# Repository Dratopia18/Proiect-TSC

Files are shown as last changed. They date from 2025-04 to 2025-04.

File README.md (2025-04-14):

# Proiect-TSC

# Diagrama Proiectului
<pre lang="markdown"> 
+-------------------------------------------+
|              POWER SECTION                |
|  +-------------+       +-----------------+|
|  | USB Type-C  |       | Charging Circuit||
|  | Connector   |------>| MCP73831        ||
|  | USB4110-GF-A|       | (Battery Mgmt)  ||
|  +-------------+       +-----------------+|
|         |                      |          |
|         v                      v          |
|  +-------------+       +-----------------+|
|  | USB to 3.3V |       | Battery Monitor ||
|  | XC6220A331MR|       | MAX17048G       ||
|  | (LDO Reg)   |       | (Fuel Gauge)    ||
|  +-------------+       +-----------------+|
|         |                                 |
+---------|---------------------------------+
          |
          v
+-----------------+        +-------------------+        +----------------+
| Interface       |        | Main Controller   |        | Memory         |
| +-------------+ |        | +---------------+ |        | +-----------+  |
| | microSD Card| |<------>| | ESP32-C6      | |<------>| | W25Q512J  |  |
| | Slot        | |        | | WROOM Module  | |        | | Flash     |  |
| +-------------+ |        | +---------------+ |        | | (64MB)    |  |
|                 |        |         |         |        |             |  |
| +-------------+ |        |         |         |        | +-----------+  |
| | FPC/FFC     | |<-------+         |         +------->| | DS3231    |  |
| | Connector   | |        |         |         |        | | RTC       |  |
| | (24-pin)    | |        |         v         |        | | w/Battery |  |
| +-------------+ |        | +---------------+ |        +----------------+
+-----------------+        | | Control Logic | |
                           | | Buttons       | |
                           | | (Reset/Boot)  | |
                           | +---------------+ |
                           +-------------------+
                                    |
                                    v
                           +-------------------+
                           | Peripherals       |
                           | +--------------+  |
                           | | BME680       |  |
                           | | Environment  |  |
                           | | Sensor (I2C) |  |
                           | +--------------+  |
                           |                   |
                           | +--------------+  |
                           | | QWIIC/I2C    |  |
                           | | Connector    |  |
                           | +--------------+  |
                           +-------------------+
</pre>

# Tabela BOM a proiectului
| Nr. | Componentă | Descriere | Furnizor | Link Achiziție | Datasheet |
|-----|---|---|---|---|---|
| 1 | ESP32-C6-WROOM-1-N8 | Microcontroller ESP32-C6 cu WiFi 6 și Bluetooth 5 | Digikey | https://www.digikey.com/en/products/detail/espressif-systems/ESP32-C6-WROOM-1-N8/17728866 | https://www.espressif.com/sites/default/files/documentation/esp32-c6-wroom-1_wroom-1u_datasheet_en.pdf |
| 2 | BME680 | Senzor integrat de mediu (temperatură, umiditate, presiune, gaz) | Digikey | https://www.digikey.com/en/products/detail/bosch-sensortec/BME680/7401317 | https://www.bosch-sensortec.com/media/boschsensortec/downloads/datasheets/bst-bme680-ds001.pdf |
| 3 | SD0805S020S1R0 | Diodă Schottky Barrier | Mouser | [https://www.mouser.com/ProductDetail/581-SD0805S020S1R0](https://ro.mouser.com/ProductDetail/KYOCERA-AVX/SD0805S020S1R0?qs=jCA%252BPfw4LHbpkAoSnwrdjw%3D%3D) | [http://datasheets.avx.com/schottky.pdf](https://ro.mouser.com/datasheet/2/40/schottky-3165252.pdf) |
| 4 | CPH3225A | Condensator 0.011F 3.3V 1210 | Digikey | https://www.digikey.com/en/products/detail/murata-electronics/CPH3225A/8692444 | [https://product.tdk.com/info/en/catalog/datasheets/mlcc_commercial_general_en.pdf](https://mm.digikey.com/Volume0/opasdata/d220001/medias/docus/6537/rev05-CPHCPM.pdf) |
| 5 | XC6220A331MR_G | Regulator de tensiune LDO | Digikey | https://www.digikey.com/en/products/detail/torex-semiconductor-ltd/XC6220A331MR-G/10165775 | https://www.torexsemi.com/file/xc6220/XC6220.pdf |
| 6 | SI1308EDL_T1_GE3 | Tranzistor MOSFET N-Channel | Digikey | https://www.digikey.com/en/products/detail/vishay-siliconix/SI1308EDL-T1-GE3/4876435 | https://www.vishay.com/docs/68734/si1308edl.pdf |
| 7 | CSR0402JTR470 | Rezistor 47 Ohm 0402 | Digikey | https://www.digikey.com/en/products/detail/stackpole-electronics-inc/CSR0402JTR470/6270526 | https://www.seielect.com/catalog/sei-rmcf_rmcp.pdf |
| 8 | KMS231GPLFS | Switch tactil | Mouser | [https://www.mouser.com/ProductDetail/611-KMS231GPLFS](https://ro.mouser.com/ProductDetail/CK/KMS231GP-LFS?qs=Qe4e1uPWiB2lCKabCZjjQg%3D%3D) | https://www.ckswitches.com/media/1464/kms.pdf |
| 9 | PGB1010603MR | Diodă de protecție ESD | Digikey | https://www.digikey.com/en/products/detail/littelfuse-inc/PGB1010603MR/715755 | https://www.littelfuse.com/~/media/electronics/datasheets/polymer_esd_suppressors/littelfuse_polymer_esd_suppressor_pgb_datasheet.pdf |
| 10 | CC0805KKX7R9BB105 | Condensator ceramic 1μF 50V | Digikey | https://www.digikey.com/en/products/detail/yageo/CC0805KKX7R9BB105/5195292 | https://www.yageo.com/upload/media/product/productsearch/datasheet/mlcc/UPY-GPHC_X7R_6.3V-to-50V_18.pdf |
| 11 | C1206C105K5RAC | Condensator ceramic 1μF 50V 1206 | Mouser | [https://www.mouser.com/ProductDetail/80-C1206C105K5R](https://ro.mouser.com/ProductDetail/KEMET/C1206C105K5RAC?qs=NTAB53G5bVDYFBtoIe7UwQ%3D%3D) | https://www.yageo.com/upload/media/product/productsearch/datasheet/mlcc/UPY-GPHC_X7R_6.3V-to-50V_18.pdf |
| 12 | C0402C105Z9VACTU | Condensator ceramic 1μF 10V 0402 | Mouser | [https://www.mouser.com/ProductDetail/80-C0402C105Z9VAC](https://ro.mouser.com/ProductDetail/KEMET/C0402C105Z9VACTU?qs=gt1LBUVyoHlQieoJt4iw1w%3D%3D) | https://www.yageo.com/upload/media/product/productsearch/datasheet/mlcc/UPY-GPHC_X5R_4V-to-50V_25.pdf |
| 13 | TAJB107K010RNJ | Condensator tantalum 100μF 10V | Digikey | https://www.digikey.com/en/products/detail/kyocera-avx/TAJB107K010RNJ/9748493 | https://componentsearchengine.com/Datasheets/1/TAJB107K010RNJ.pdf |
| 14 | C0402C475M9PACTU | Condensator ceramic 4.7μF 6.3V 0402 | Mouser | [https://www.mouser.com/ProductDetail/80-C0402C475M9PAC](https://ro.mouser.com/ProductDetail/KEMET/C0402C475M9PACTU?qs=x4XeXhDQKnr0GX0Xu9DUoQ%3D%3D) | https://www.yageo.com/upload/media/product/productsearch/datasheet/mlcc/UPY-GPHC_Y5V_6.3V-to-50V_20.pdf |
| 15 | DMG2305UX_7 | Tranzistor MOSFET P-Channel | Digikey | https://www.digikey.com/en/products/detail/diodes-incorporated/DMG2305UX-7/4340667 | https://www.diodes.com/assets/Datasheets/DMG2305UX.pdf |
| 16 | WCR0402-100KFA | Rezistor 100k Ohm 0402 | Mouser | [https://www.mouser.com/ProductDetail/652-WCR0402-100KFA](https://ro.mouser.com/ProductDetail/Welwyn-Components-TT-Electronics/WCR0402-100KFA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) | https://www.welwyn-tt.com/wp-content/uploads/2020/07/Welwyn_WCR_Series_-_Issue_5_-_April_2020.pdf |
| 17 | PFMF.050.2 | Siguranță PTC resetabilă | Mouser | [https://www.mouser.com/ProductDetail/652-PFMF.050.2](https://ro.mouser.com/ProductDetail/Schurter/PFMF.050.2?qs=1auRipcfynCums5v1iucSA%3D%3D) | https://www.littelfuse.com/~/media/electronics/datasheets/resettable_ptcs/littelfuse_ptc_pfmf_datasheet.pdf |
| 18 | 744043680 | Inductor de putere 68μH | Mouser | [https://www.mouser.com/ProductDetail/710-744043680](https://ro.mouser.com/ProductDetail/Wurth-Elektronik/744043680?qs=PGXP4M47uW6VkZq%252BkzjrHA%3D%3D) | https://www.we-online.com/components/products/datasheet/744043680.pdf |
| 19 | MBR0530T3G | Diodă Schottky 0.5A 30V | Mouser | [https://www.mouser.com/ProductDetail/863-MBR0530T3G](https://ro.mouser.com/ProductDetail/onsemi/MBR0530T3G?qs=3JMERSakebpEmdUS6GetdQ%3D%3D) | https://www.onsemi.com/pdf/datasheet/mbr0530t1-d.pdf |
| 20 | SM04B_SRSS_TB | Conector JST SH 4 pini SMD | Digikey | https://www.digikey.com/en/products/detail/jst-sales-america-inc/SM04B-SRSS-TB-LF-SN/926710 | https://www.jst-mfg.com/product/pdf/eng/eSH.pdf |
| 21 | MAX17048G_T10 | Monitor de baterie Li+ | Digikey | https://www.digikey.com/en/products/detail/analog-devices-inc-maxim-integrated/MAX17048G-T10/3758921 | https://datasheets.maximintegrated.com/en/ds/MAX17048-MAX17049.pdf |
| 22 | MCP73831T_2ACI_OT | Controller de încărcare Li-Ion/Li-Polymer | Digikey | https://www.digikey.com/en/products/detail/microchip-technology/MCP73831T-2ACI-OT/964301 | https://ww1.microchip.com/downloads/en/DeviceDoc/MCP73831-Family-Data-Sheet-DS20001984H.pdf |
| 23 | BD5229G-TR | Detector de tensiune cu timp de întârziere ajustabil | Digikey | https://www.digikey.com/en/products/detail/rohm-semiconductor/BD5229G-TR/658502 | https://fscdn.rohm.com/en/products/databook/datasheet/ic/power/voltage_detector/bd52xxg-e.pdf |
| 24 | DS3231SN# | RTC (Real Time Clock) Serial | Digikey | https://www.digikey.com/en/products/detail/analog-devices-inc-maxim-integrated/DS3231SN/1197576 | https://datasheets.maximintegrated.com/en/ds/DS3231.pdf |
| 25 | W25Q512JVEIQ | Memorie Flash SPI 512Mbit | Digikey | https://www.digikey.com/en/products/detail/winbond-electronics/W25Q512JVEIQ/10244706 | https://www.winbond.com/resource-files/w25q512jv%20revf%2010142020%20plus.pdf |
| 26 | FH34SRJ-24S-0.5SH(99) | Conector FPC 24 pini | Mouser | [https://www.mouser.com/ProductDetail/798-FH34SRJ24S05SH99](https://ro.mouser.com/ProductDetail/Hirose-Connector/FH34SRJ-24S-0.5SH99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) | https://www.hirose.com/product/document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 |
| 27 | C0402C104K4RACTU | Condensator ceramic 0.1μF 16V 0402 | Digikey | https://www.digikey.com/en/products/detail/kyocera-avx/C0402C104K4RACTU/789653 | https://ds.yuden.co.jp/TYCOMPAS/ut/download?pn=CC0402JRNPO9BN220&fileType=CA |
| 28 | USBLC6-2SC6Y | Circuit de protecție ESD pentru USB | Digikey | https://www.digikey.com/en/products/detail/stmicroelectronics/USBLC6-2SC6Y/2819177 | https://www.st.com/resource/en/datasheet/usblc6-2.pdf |
| 29 | USB4110-GF-A | Conector USB Type-C | Digikey | https://www.digikey.com/en/products/detail/gct/USB4110-GF-A/10384547 | https://gct.co/connector/usb4110 |
| 30 | 112A-TAAR-R03 | Conector pentru antenă | Digikey | https://www.digikey.com/en/products/detail/linx-technologies-inc/112A-TAAR-R03/17633923 | https://linxtechnologies.com/wp/wp-content/uploads/112-series-data-sheet.pdf |

# Descrierea Funcționalității Hardware

## Modulul Microcontroller

Proiectul este bazat pe modulul ESP32-C6-WROOM-1-N8, un microcontroller de ultimă generație care include WiFi 6 și Bluetooth 5. Acest modul oferă performanțe excelente și un consum de energie redus, fiind ideal 
pentru aplicații IoT.

## Senzori

BME680 - un senzor integrat de mediu produs de Bosch Sensortec care măsoară:

* Temperatura (între -40°C și +85°C)
* Umiditatea relativă (între 0% și 100%)
* Presiunea barometrică (între 300hPa și 1100hPa)
* Calitatea aerului (prin măsurarea compușilor organici volatili)

Senzorul se conectează la ESP32-C6 prin interfața I2C, utilizând pinii SDA și SCL.

DS3231SN - un Real Time Clock (RTC) de înaltă precizie:

* Menține data și ora precisă
* Include compensare de temperatură
* Interfațare prin I2C
* Backup cu baterie pentru păstrarea timpului când alimentarea principală este întreruptă

## Sistemul de Alimentare

Încărcător de baterie Li-Ion/Li-Polymer:

* Controller dedicat MCP73831T-2ACI-OT
* LED indicator pentru starea încărcării
* Circuite de protecție pentru baterie

Management Energie:

* Regulator LDO XC6220A331MR_G pentru alimentare stabilă 3.3V
* Detector de tensiune BD5229G-TR pentru monitorizarea nivelului bateriei
* Monitor de baterie MAX17048G_T10 pentru măsurarea precisă a nivelului de încărcare
* Circuite de protecție PTC (PFMF.050.2) pentru protecție la supracurent

Convertoare DC-DC:
* Inductori de putere (744043680) pentru conversia eficientă a tensiunii
* Diode Schottky (SD0805S020S1R0, MBR0530T3G) pentru circuitele de comutație

## Stocare
Sistemul include memoria flash W25Q512JVEIQ de 512Mbit (64MB) conectată prin interfața SPI, oferind:

* Spațiu amplu pentru logging de date
* Viteză mare de citire/scriere (până la 104 MHz în mod SPI)
* Suport pentru modul Quad SPI pentru transfer de date accelerat
* Durată de retenție a datelor de peste 20 de ani

## Conectivitate

USB Type-C:

* Conector USB4110-GF-A pentru încărcare și comunicare
* Circuit de protecție USBLC6-2SC6Y pentru protecție ESD
* Suport pentru comunicare serială prin UART

Interfață FPC:

* Conector FH34SRJ-24S-0.5SH(99) cu 24 de pini
* Permite conectarea modulelor de expansiune sau a ecranelor
* Accesează multiple interfețe (I2C, SPI, GPIO)

Conectivitate Wireless:

* WiFi 6 integrat în modulul ESP32-C6
* Bluetooth 5.0 pentru conectivitate la dispozitive mobile
* Conector pentru antenă externă 112A-TAAR-R03 pentru îmbunătățirea recepției

## Interfața Utilizator

Butoane Tactile:

* Buton de boot (KMS231GPLFS) pentru intrarea în modul de programare
* Buton de reset (KMS231GPLFS) pentru repornirea sistemului
* Butoane adiționale configurabile de utilizator

LED-uri de Status:

* LED pentru indicarea stării de încărcare
* LED pentru indicarea activității sistemului
* LED-uri configurabile pentru notificări personalizate

# Pinii ESP32-C6: Functia si utilizarea fiecarui pin

| Pin | Funcție | Modul de utilizare |
|---|---|---|
| 3V3 | Supply | Furnizează tensiune de 3.3V pentru componente. |
| GND | Ground | Referință pentru circuit. |
| EN | Enable | Permite pornirea/resetarea modulului (tensiune ridicată = activ).|
| IO0 | INT_RTC (Interrupt) | Pentru notificări, conectat la modulul RTC. |
| IO1 | RTC CLK | Semnal de ceas pentru modulul RTC. |
| IO2 | SPI MISO | Primire date de la periferice conectate prin SPI. |
| IO3 | Status | Semnalizează starea de ocupare a display-ului. |
| IO4 | Slave Select | Selectează cardul SD. |
| IO5 | Data/Command | Selectează între modul de date și comenzi. |
| IO6 | SPI CLK | Semnal de ceas pentru SPI. |
| IO7 | SPI MOSI | Transfer date către periferice conectate prin SPI. |
| IO8 | GPIO | Pin general GPIO. |
| IO9 | IO/BOOT | Conectat la un buton pentru intrarea în modul de boot. |
| IO10 | EPD_CS  (Chip Select) | Activează comunicarea cu display-ul. |
| IO11 | FLASH_CS (Chip Select) | Activează comunicarea cu memoria flash. |
| IO12 | USB_D- | Pentru USB. |
| IO13 | USB_D+ | Pentru USB. |
| IO15 | IO/CHANGE | Conectat la un buton. |
| IO16 | TX | Pentru UART. |
| IO17 | RX | Pentru UART. |
| IO18 | RTC_RST | Pentru resetarea modulului RTC. |
| IO19 | I2C_PW | Supply pentru I2C. |
| IO20 | EPD_3V3_C | Alimentare display. |
| IO21 | SDA | Linia de date pentru I2C. |
| IO22 | SCL | Semnalul de ceas pentru I2C. |
| IO23 | EPD_RST | Pentru resetarea display-ului. |

## Calcule de Consum Energetic

Consumul în diferite moduri de operare:

Mod Activ (Toate funcțiile active):

* ESP32-C6: ~60mA @ 3.3V
* BME680: ~3.7mA în mod activ
* DS3231: ~0.15mA
* Memorie Flash: ~15mA în operație de scriere
* Monitor baterie: ~0.5mA
* Circuite adiționale: ~5mA

Total mod activ: ~84.35mA @ 3.3V = 278.35mW

Mod Normal (Funcționare tipică):

* ESP32-C6: ~35mA (WiFi activ, procesor la viteză medie)
* BME680: ~1mA (măsurători periodice)
* DS3231: ~0.15mA
* Memorie Flash: ~1mA (operații ocazionale)
* Circuite adiționale: ~3mA

Total mod normal: ~40.15mA @ 3.3V = 132.5mW

Mod Sleep (Economisire energie):

* ESP32-C6: ~10μA (deep sleep)
* BME680: ~0.15μA (sleep)
* DS3231: ~0.15mA (activ pentru menținerea timpului)
* Circuite adiționale: ~50μA

Total mod sleep: ~0.21mA @ 3.3V = 0.693mW

Durata de viață a bateriei:

Considerând o baterie Li-Po de 1200mAh:

* În mod activ: ~14.2 ore
* În mod normal: ~29.9 ore
* Cu ciclu de funcționare optimizat (10% mod normal, 90% mod sleep): ~8-10 zile

# Design PCB și Considerații Mecanice

Dimensiuni PCB:

* Dimensiuni totale: 80mm x 40mm
* Grosime PCB: 1 mm
* Straturi: 3 (Top, Dielectrical, Bottom)

Considerații Termice:

* Componentele cu disipare mare de căldură (regulatoare, încărcător baterie) plasate cu zone de disipare adecvate
* Vias termice sub ESP32-C6 pentru disiparea căldurii

Layout Componente:

* Secțiune RF (antenă WiFi/BT) izolată și optimizată pentru performanță
* Separarea circuitelor digitale de cele analogice pentru minimizarea interferențelor
* Componente sensibile la zgomot (senzori) plasate departe de surse de interferență
* Integrarea ESP32-C6 oferă capabilități WiFi 6 și Bluetooth de ultimă generație
* Senzorul BME680 permite monitorizarea completă a parametrilor de mediu
* Sistemul de management al energiei optimizat pentru durată lungă de funcționare
* Conectorul FPC permite extensibilitate și adăugarea de module viitoare

Perspective de dezvoltare:

* Adăugarea unui ecran E-Ink pentru afișare cu consum ultra-redus
* Implementarea unui încărcător solar pentru autonomie completă
* Dezvoltarea de module de expansiune specifice pentru diverse aplicații
* Optimizarea și mai pronunțată a consumului energetic pentru funcționare pe termen lung

Limitări actuale:

* Dimensiunile pot fi reduse în versiunile viitoare
* Costuri de producție pot fi optimizate prin reducerea numărului de componente
* Protecție IP limitată fără carcasă dedicată

# Concluzie
Proiectul actual reprezintă o platformă de dezvoltare IoT completă, bazată pe ESP32-C6, cu capabilități extinse de senzori, managementul energiei, și opțiuni de conectivitate. Design-ul hardware a fost realizat
cu accent pe eficiență energetică, flexibilitate și fiabilitate, permițând o gamă largă de aplicații de la monitorizarea mediului până la controlul automatizărilor.

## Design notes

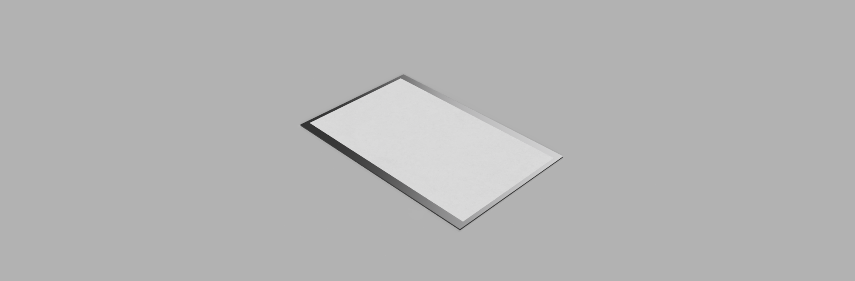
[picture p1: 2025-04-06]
Images/Ecran Tableta OpenBook.png

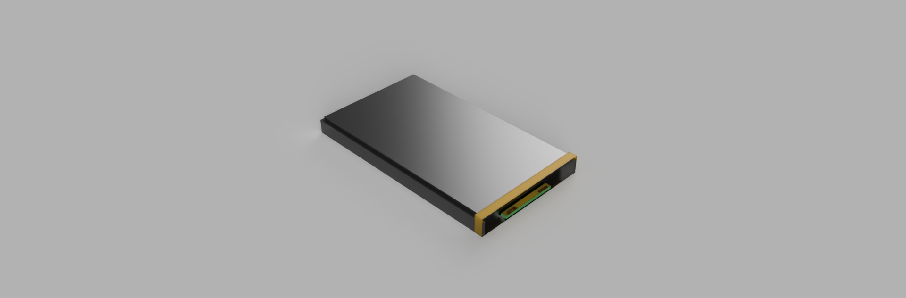
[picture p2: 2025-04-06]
Images/Baterie Tableta OpenBook.png

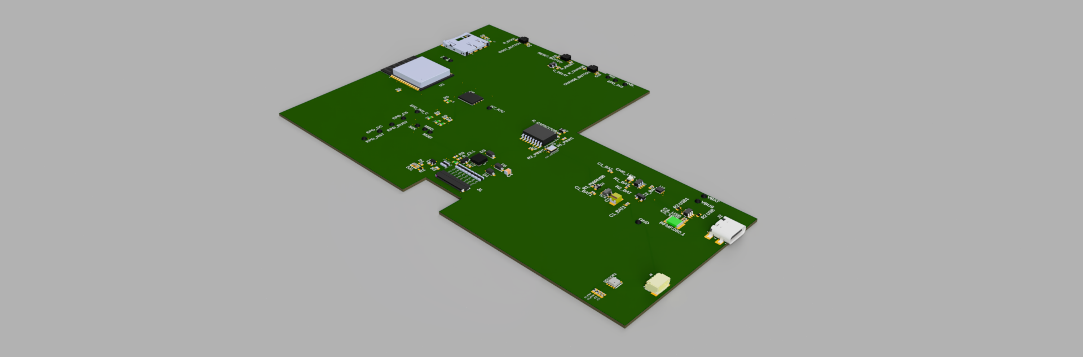
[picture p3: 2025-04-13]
Images/PCB Tableta OpenBook.png

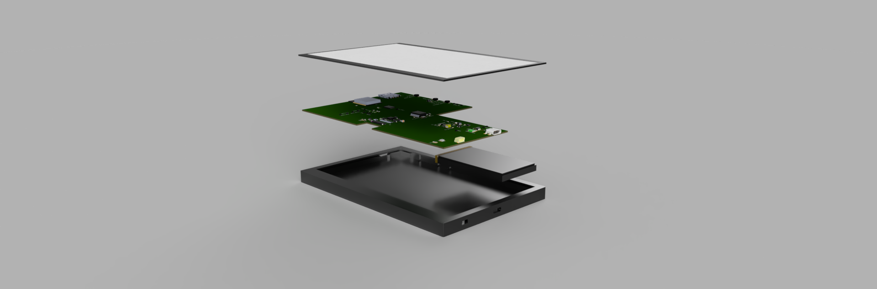
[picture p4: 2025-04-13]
Images/Tableta OpenBook - exploded view.png

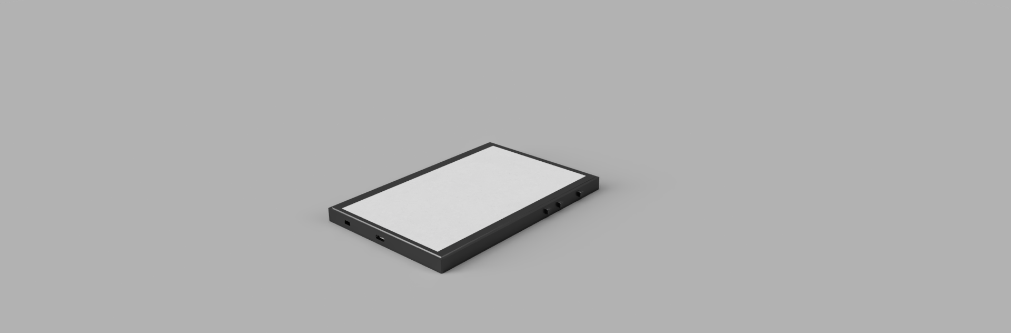
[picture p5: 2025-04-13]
Images/Tableta OpenBook.png

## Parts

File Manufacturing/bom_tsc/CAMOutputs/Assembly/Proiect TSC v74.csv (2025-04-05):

Qty | Value | Device | Package | Parts | Description | ARROW_PART_NUMBER | ARROW_PRICE-STOCK | AVAILABILITY | CENTROID_NOT_SPECIFIED | CHECK_PRICES | COPYRIGHT | DATASHEET | DESCRIPTION | DIGIKEY_DESCRIPTION | DIGIKEY_PART_NUMBER | HEIGHT | LEAD_FREE | MANUFACTURER_NAME | MANUFACTURER_PART_NUMBER | MF | MFR_NAME | MOUSER_PART_NUMBER | MOUSER_PRICE-STOCK | MOUSER_TESTING_PART_NUMBER | MOUSER_TESTING_PRICE-STOCK | MP | MPN | PACKAGE | POPULARITY | PREFIX | PRICE | PROD_ID | PURCHASE-URL | ROHS | SNAPEDA_LINK | SPICEMODEL | SPICEPREFIX | TEMPERATURE_RANGE_HIGH | TEMPERATURE_RANGE_LOW | TP_SIGNAL_NAME | VALUE
1 |  | ADAFRUIT_LEDCHIP-LED0603 | ADAFRUIT_CHIP-LED0603 | CHG_LED | LED
1 |  | SJ | SJ | SJ1 | SMD solder JUMPER |  |  |  |  |  |  |  |  |  |  |  |  |  |  |  |  |  |  |  |  |  |  |  | 3
1 | 0.47 | ESP32_WROVER_EAGLE-LTSPICE_RR0402 | ESP32_WROVER_EAGLE-LTSPICE_R0402 | R3 | RESISTOR, European symbol |  |  |  |  |  |  |  |  |  |  |  |  |  |  |  |  |  |  |  |  |  |  |  |  |  |  |  |  |  |  | NONE | R
1 | 100K | ESP32_WROVER_EAGLE-LTSPICE_RR0402 | ESP32_WROVER_EAGLE-LTSPICE_R0402 | R1_PWRUSB | RESISTOR, European symbol |  |  |  |  |  |  |  |  |  |  |  |  |  |  |  |  |  |  |  |  |  |  |  |  |  |  |  |  |  |  | NONE | R
4 | 100nF | EAGLE-LTSPICE_CC0402 | EAGLE-LTSPICE_C0402 | C6, C8, C10, C_DELAY | CAPACITOR, European symbol |  |  |  |  |  |  |  |  |  |  |  |  |  |  |  |  |  |  |  |  |  |  |  |  |  |  |  |  |  |  | NONE | C
5 | 100nF | ESP32_WROVER_EAGLE-LTSPICE_CC0402 | ESP32_WROVER_EAGLE-LTSPICE_C0402 | C1, C2, C4_USB, C5_USB, C9 | CAPACITOR, European symbol |  |  |  |  |  |  |  |  |  |  |  |  |  |  |  |  |  |  |  |  |  |  |  |  |  |  |  |  |  |  | NONE | C
1 | 100uF TANT | RCL_CPOL-EUCT3528 | RCL_CT3528 | C3 | POLARIZED CAPACITOR, European symbol |  |  |  |  |  |  |  |  |  |  |  |  |  |  |  |  |  |  |  |  |  |  |  | 0 |  |  |  |  |  |  |  | C
15 | 10K | ESP32_WROVER_EAGLE-LTSPICE_RR0402 | ESP32_WROVER_EAGLE-LTSPICE_R0402 | R1, R1_PINH, R1_PINH1, R2_PINH, R2_PINH1, R5, R6, R7, R8, R9, R10, R_BOOT, R_CHANGE, R_CL1, R_RESET | RESISTOR, European symbol |  |  |  |  |  |  |  |  |  |  |  |  |  |  |  |  |  |  |  |  |  |  |  |  |  |  |  |  |  |  | NONE | R
1 | 10k | ESP32_WROVER_EAGLE-LTSPICE_RR0402 | ESP32_WROVER_EAGLE-LTSPICE_R0402 | R4 | RESISTOR, European symbol |  |  |  |  |  |  |  |  |  |  |  |  |  |  |  |  |  |  |  |  |  |  |  |  |  |  |  |  |  |  | NONE | R
1 | 10uF | EAGLE-LTSPICE_CC0402 | EAGLE-LTSPICE_C0402 | C7 | CAPACITOR, European symbol |  |  |  |  |  |  |  |  |  |  |  |  |  |  |  |  |  |  |  |  |  |  |  |  |  |  |  |  |  |  | NONE | C
1 | 112A-TAAR-R03_ATTEND | 112A-TAAR-R03_ATTEND | 112ATAARR03ATTEND | J4 | Micro SD Card Socket, Push-Push Type, Top Mount, SMT, H=1.83mm, 10u |  |  |  |  |  |  |  | Micro SD Card Socket | Push-Push Type | Top Mount | SMT | H=1.83mm | 10u |  |  | 1.9mm |  | ATTEND | 112A-TAAR-R03 ATTEND
1 | 15 | ESP32_WROVER_EAGLE-LTSPICE_RR0402 | ESP32_WROVER_EAGLE-LTSPICE_R0402 | R_CAPACITOR | RESISTOR, European symbol |  |  |  |  |  |  |  |  |  |  |  |  |  |  |  |  |  |  |  |  |  |  |  |  |  |  |  |  |  |  | NONE | R
1 | 1uF | EAGLE-LTSPICE_CC0402 | EAGLE-LTSPICE_C0402 | C5 | CAPACITOR, European symbol |  |  |  |  |  |  |  |  |  |  |  |  |  |  |  |  |  |  |  |  |  |  |  |  |  |  |  |  |  |  | NONE | C
10 | 1uF/50V | ESP32_WROVER_EAGLE-LTSPICE_CC0402 | ESP32_WROVER_EAGLE-LTSPICE_C0402 | EPD_C1, EPD_C2, EPD_C5, EPD_C6, EPD_C7, EPD_C8, EPD_C9, EPD_C10, EPD_C11, EPD_C12 | CAPACITOR, European symbol |  |  |  |  |  |  |  |  |  |  |  |  |  |  |  |  |  |  |  |  |  |  |  |  |  |  |  |  |  |  | NONE | C
1 | 2.2 | ESP32_WROVER_EAGLE-LTSPICE_RR0402 | ESP32_WROVER_EAGLE-LTSPICE_R0402 | R2 | RESISTOR, European symbol |  |  |  |  |  |  |  |  |  |  |  |  |  |  |  |  |  |  |  |  |  |  |  |  |  |  |  |  |  |  | NONE | R
1 | 200 | ESP32_WROVER_EAGLE-LTSPICE_RR0402 | ESP32_WROVER_EAGLE-LTSPICE_R0402 | R1_BAT | RESISTOR, European symbol |  |  |  |  |  |  |  |  |  |  |  |  |  |  |  |  |  |  |  |  |  |  |  |  |  |  |  |  |  |  | NONE | R
2 | 20V/4.2A/52mO/1.4W | ESP32_WROVER_SPARKFUN-DISCRETESEMI_MOSFET_PCH-DMG2305UX-7 | ESP32_WROVER_SPARKFUN-DISCRETESEMI_SOT23-3 | Q1, Q2 | P-channel MOSFETs |  |  |  |  |  |  |  |  |  |  |  |  |  |  |  |  |  |  |  |  |  |  |  |  |  |  | TRAN-14388 |  |  |  |  |  |  |  |  | 20V/4.2A/52mO/1.4W
1 | 2K | ESP32_WROVER_EAGLE-LTSPICE_RR0402 | ESP32_WROVER_EAGLE-LTSPICE_R0402 | R2_BAT | RESISTOR, European symbol |  |  |  |  |  |  |  |  |  |  |  |  |  |  |  |  |  |  |  |  |  |  |  |  |  |  |  |  |  |  | NONE | R
4 | 4.7uF | ESP32_WROVER_EAGLE-LTSPICE_CC0402 | ESP32_WROVER_EAGLE-LTSPICE_C0402 | C1_BAT, C1_BAT1, C1_BAT2, C2_BAT | CAPACITOR, European symbol |  |  |  |  |  |  |  |  |  |  |  |  |  |  |  |  |  |  |  |  |  |  |  |  |  |  |  |  |  |  | NONE | C
1 | 4.7uF/25V | ESP32_WROVER_EAGLE-LTSPICE_CC0402 | ESP32_WROVER_EAGLE-LTSPICE_C0402 | C4 | CAPACITOR, European symbol |  |  |  |  |  |  |  |  |  |  |  |  |  |  |  |  |  |  |  |  |  |  |  |  |  |  |  |  |  |  | NONE | C
2 | 5k1 | ESP32_WROVER_EAGLE-LTSPICE_RR0402 | ESP32_WROVER_EAGLE-LTSPICE_R0402 | R2-USB, R2-USB1 | RESISTOR, European symbol |  |  |  |  |  |  |  |  |  |  |  |  |  |  |  |  |  |  |  |  |  |  |  |  |  |  |  |  |  |  | NONE | R
1 | 68uH | 744043680IND_4828-WE-TPC_WRE | IND_4828-WE-TPC_WRE | L1 |  |  |  |  |  |  | Copyright (C) 2024 Ultra Librarian. All rights reserved. |  |  |  |  |  |  |  | 744043680 |  | Wurth Electronics
1 | BD5229G-TR | BD5229G-TR | SOT95P280X125-5N | IC1 | Voltage Detector with Adjustable Delay Time: CMOS processes are utilized to develop high precision, low current consumption CMOS reset ICs that allow arbitrary setting of the delay time. The extensive lineup includes both Nch Open Drain and CMOS output types in a wide range of detection voltages (from 2.3V to 6.0V, in 0.1V steps), enabling selection of the ideal solution based on customer requirements. In addition, the entire series is of course both lead-free and RoHS-compliant. |  |  |  |  |  |  |  | Voltage Detector with Adjustable Delay Time: CMOS processes are utilized to develop high precision | low current consumption CMOS reset ICs that allow arbitrary setting of the delay time. The extensive lineup includes both Nch Open Drain and CMOS output types in a wide range of detection voltages (from 2.3V to 6.0V | in 0.1V steps) | enabling selection of the ideal solution based on customer requirements. In addition | the entire series is of course both lead-free and RoHS-compliant. |  |  | 1.25mm |  | ROHM Semiconductor | BD5229G-TR |  |  | 755-BD5229G-TR | https://www.mouser.co.uk/ProductDetail/ROHM-Semiconductor/BD5229G-TR?qs=4kLU8WoGk0vvnhrrYwdszw%3D%3D
3 | BUTTON_CUSYOMV1 | BUTTON_CUSYOMV1 | MYBUTTON | BOOT_BUTTON, CHANGE_BUTTON, RESET_BUTTON
1 | CPH3225A | CPH3225A | CAPCP3225X100N | C10_SUPERCAP | Cap 0.011F 3.3V 1210 Flat Check availability |  |  | Not in stock |  | https://www.snapeda.com/parts/CPH3225A/Seiko+Instruments/view-part/?ref=eda |  |  | 11 mF (EDLC) Supercapacitor 3.3 V 1210 (3225 Metric) - - |  |  |  |  |  |  | Seiko Instruments |  |  |  |  |  | CPH3225A |  | 1210 Seiko |  |  | None |  | https://www.snapeda.com/api/url_track_click_mouser/?unipart_id=562593&manufacturer=Seiko Instruments&part_name=CPH3225A&search_term=None |  | https://www.snapeda.com/parts/CPH3225A/Seiko+Instruments/view-part/?ref=snap
1 | DS3231SN# | DS3231SN# | SOIC127P1032X265-16N | U3 | Real Time Clock Serial 16-Pin SOIC W T/R Check availability |  |  | In Stock |  | https://www.snapeda.com/parts/DS3231SN%23/Analog+Devices/view-part/?ref=eda |  |  | Extremely Accurate I²C-Integrated RTC/TCXO/Crystal |  |  |  |  |  |  | Analog Devices |  |  |  |  |  | DS3231SN# |  | SOIC-16 Maxim |  |  | None |  | https://www.snapeda.com/api/url_track_click_mouser/?unipart_id=99048&manufacturer=Analog Devices&part_name=DS3231SN#&search_term=None |  | https://www.snapeda.com/parts/DS3231SN%23/Analog+Devices/view-part/?ref=snap
1 | ESP32-C6-WROOM-1-N8 | ESP32-C6-WROOM-1-N8 | XCVR_ESP32-C6-WROOM-1-N8 | U2 | Check availability |  |  | In Stock |  | https://www.snapeda.com/parts/ESP32-C6-WROOM-1-N8/Espressif+Systems/view-part/?ref=eda |  |  | Multiprotocol Modules ESP32-C6 module | Wi-Fi 6 in 2.4 GHz band | Bluetooth 5 | Zigbee 3.0 and Thread. ESP34-WROOM Compatible - ENGINEERING SAMPLE |  |  |  |  |  |  | Espressif Systems |  |  |  |  |  | ESP32-C6-WROOM-1-N8 |  | None |  |  | None |  |  |  | https://www.snapeda.com/parts/ESP32-C6-WROOM-1-N8/Espressif+Systems/view-part/?ref=snap
1 | ESP32C6_VARISTORCN1812 | ESP32C6_VARISTORCN1812 | ESP32C6_VARISTOR_CT/CN1812 | PFMF.050.1 | VARISTOR |  |  |  |  |  |  |  |  |  |  |  |  |  |  |  |  |  |  |  |  |  |  |  | 0
2 | ESP32_WROVER_AVX---SD0805S020S1R0_AVX_SD0805S020S1R0_0_0AVX_SD0805S020S1R0_0_0 | ESP32_WROVER_AVX---SD0805S020S1R0_AVX_SD0805S020S1R0_0_0AVX_SD0805S020S1R0_0_0 | ESP32_WROVER_AVX---SD0805S020S1R0_AVX_SD0805S020S1R0_0 | D2, D7 | Schottky Barrier Rectifier Diode |  |  |  | No |  |  | http://datasheets.avx.com/schottky.pdf |  | DIODE SCHOTTKY 20V 1A 0805 | 478-7800-1-ND |  | yes |  |  | AVX |  | 581-SD0805S020S1R0 |  |  |  |  |  | 0805 (2012 metric) |  | D |  |  |  | yes |  |  |  | +125°C | -55°C
1 | ESP32_WROVER_BME680_BME680 | ESP32_WROVER_BME680_BME680 | ESP32_WROVER_BME680_PSON80P300X300X100-8N | SENSOR2 | Integrated Environmental Unit |  |  | Unavailable |  |  |  |  | Integrated Environmental Unit |  |  |  |  |  |  | Bosch Sensortec |  |  |  |  |  | BME680 |  | LGA-8 Bosch Tools |  |  | None
1 | ESP32_WROVER_SPARKFUN-IC-POWER_MCP73831 | ESP32_WROVER_SPARKFUN-IC-POWER_MCP73831 | ESP32_WROVER_SPARKFUN-IC-POWER_SOT23-5 | MCP73831 | MCP73831T Li-Ion, Li-Pol Controller |  |  |  |  |  |  |  |  |  |  |  |  |  |  |  |  |  |  |  |  |  |  |  |  |  |  | IC-09995
1 | FH34SRJ-24S-0.5SH_99_ | FH34SRJ-24S-0.5SH_99_ | FH34SRJ24S05SH99 | J1 | (0.50mm) Surface Mount, Right Angle |  |  |  |  |  |  |  | 24 Position FFC | FPC Connector Contacts | (0.50mm) Surface Mount | Right Angle |  |  | 1.1mm |  | Hirose | FH34SRJ-24S-0.5SH(99) |  |  | 798-FH34SRJ24S05SH99 | https://www.mouser.co.uk/ProductDetail/Hirose-Connector/FH34SRJ-24S-0.5SH99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
1 | MAX17048G+T10 | MAX17048G+T10 | SON50P200X200X80-9N | U4 | Check availability |  |  | In Stock |  | https://www.snapeda.com/parts/MAX17048G+T10/Analog+Devices/view-part/?ref=eda |  |  | 3µA 1-Cell/2-Cell Fuel Gauge with ModelGauge |  |  |  |  |  |  | Analog Devices |  |  |  |  |  | MAX17048G+T10 |  | TDFN-8 Maxim |  |  | None |  | https://www.snapeda.com/api/url_track_click_mouser/?unipart_id=329239&manufacturer=Analog Devices&part_name=MAX17048G+T10&search_term=None |  | https://www.snapeda.com/parts/MAX17048G+T10/Analog+Devices/view-part/?ref=snap
3 | MBR0530 | MBR0530 | SOD3716X135N | D3, D4, D5 | ON SEMICONDUCTOR - MBR0530 - DIODE, SCHOTTKY, 0.5A, 30V, SOD-123 |  |  | In Stock |  | https://www.snapeda.com/parts/MBR0530/Onsemi/view-part/?ref=eda |  |  | Diode Schottky 30 V 500mA Surface Mount SOD-123 |  |  |  |  |  |  | ON Semiconductor |  |  |  |  |  | MBR0530 |  | SOD-123-2 ON Semiconductor |  |  | None |  | https://www.snapeda.com/api/url_track_click_mouser/?unipart_id=179458&manufacturer=ON Semiconductor&part_name=MBR0530&search_term=None |  | https://www.snapeda.com/parts/MBR0530/Onsemi/view-part/?ref=snap
6 | PGB1010603MR | PGB1010603MR | DIOC1608X36N | D6, D8, D9, D10, D11, D12 | Check availability |  |  | In Stock |  | https://www.snapeda.com/parts/PGB1010603MR/Littelfuse/view-part/?ref=eda |  |  | 150V (Typ) Clamp - Ipp Tvs Diode Surface Mount 0603 (1608 Metric) |  |  |  |  |  |  | Littelfuse Inc. |  |  |  |  |  | PGB1010603MR |  | 0603 Littelfuse Inc. |  |  | None |  | https://www.snapeda.com/api/url_track_click_mouser/?unipart_id=5659453&manufacturer=Littelfuse Inc.&part_name=PGB1010603MR&search_term=None |  | https://www.snapeda.com/parts/PGB1010603MR/Littelfuse/view-part/?ref=snap
1 | QWIIC_RIGHT_ANGLE | QWIIC_CONNECTORJS-1MM | JST04_1MM_RA | J3 | SparkFun I2C Standard Qwiic Connector |  |  |  |  |  |  |  |  |  |  |  |  |  |  |  |  |  |  |  |  |  |  |  |  |  |  | CONN-13694 |  |  |  |  |  |  |  |  | QWIIC_RIGHT_ANGLE
1 | SAMACSYS_PARTS_USB4110-GF-A | SAMACSYS_PARTS_USB4110-GF-A | SAMACSYS_PARTS_USB4110GFA | J2 | CONN USB 2.0 TYPE-C R/A SMT |  |  |  |  |  |  |  | CONN USB 2.0 TYPE-C R/A SMT |  |  | 3.26mm |  | GCT (GLOBAL CONNECTOR TECHNOLOGY) | USB4110-GF-A |  |  | 640-USB4110-GF-A | https://www.mouser.co.uk/ProductDetail/GCT/USB4110-GF-A?qs=KUoIvG%2F9IlYiZvIXQjyJeA%3D%3D
1 | SI1308EDL-T1-GE3 | SI1308EDL-T1-GE3 | SOT65P210X110-3N | Q3 | MOSFET N-Ch 30V 1.5A TrenchFET SC70 Vishay Si1308EDL-T1-GE3 N-channel MOSFET Transistor, 1.5 A, 30 V, 3-Pin SC-70 |  |  | In Stock |  | https://www.snapeda.com/parts/SI1308EDL-T1-GE3/Vishay+Siliconix/view-part/?ref=eda |  |  | Si1308EDL-T1-GE3 N-channel MOSFET Transistor | 1.5 A | 30 V | 3-Pin SC-70 | Siliconix / Vishay SI1308EDL-T1-GE3 |  |  |  |  |  |  | Vishay Siliconix |  |  |  |  |  | SI1308EDL-T1-GE3 |  | SOT-323 Vishay Semiconductor |  |  | None |  | https://www.snapeda.com/api/url_track_click_mouser/?unipart_id=274603&manufacturer=Vishay Siliconix&part_name=SI1308EDL-T1-GE3&search_term=None |  | https://www.snapeda.com/parts/SI1308EDL-T1-GE3/Vishay+Siliconix/view-part/?ref=snap
17 | TPTP20R | TPTP20R | TP20R | TP1, TP2, TP3, TP4, TP5, TP6, TP7, TP8, TP9, TP10, TP11, TP12, TP13, TP14, TP15, TP16, TP17 | Test pad |  |  |  |  |  |  |  |  |  |  |  |  |  |  |  |  |  |  |  |  |  |  |  | 2
1 | USBLC6-2SC6Y | USBLC6-2SC6Y | SOT95P280X145-6N | D1 | Low Cap. ESD Protection Auto SOT-23-6 STMicroelectronics USBLC6-2SC6Y, Dual Uni-Directional TVS Diode Array, 6-Pin SOT-23 |  |  | In Stock |  | https://www.snapeda.com/parts/USBLC6-2SC6Y/STMicroelectronics/view-part/?ref=eda |  |  | 17V Clamp 5A (8/20µs) Ipp Tvs Diode Surface Mount SOT-23-6 |  |  |  |  |  |  | STMicroelectronics |  |  |  |  |  | USBLC6-2SC6Y |  | SOT-23-6 STMicroelectronics |  |  | None |  |  |  | https://www.snapeda.com/parts/USBLC6-2SC6Y/STMicroelectronics/view-part/?ref=snap
1 | W25Q512JVEIQ | W25Q512JVEIQ | SON127P600X800X80-9N | U6 | Check availability |  |  | In Stock |  | https://www.snapeda.com/parts/W25Q512JVEIQ/Winbond+Electronics/view-part/?ref=eda |  |  | FLASH - NOR Memory IC 512Mb (64M x 8) SPI - Quad I/O 133 MHz 8-WSON (8x6) |  |  |  |  |  |  | Winbond Electronics |  |  |  |  |  | W25Q512JVEIQ |  | Package |  |  | None |  |  |  | https://www.snapeda.com/parts/W25Q512JVEIQ/Winbond+Electronics/view-part/?ref=snap
1 | XC6220A331MR-G | XC6220A331MR-G | SOT95P280X120-5N | IC4 | LDO Voltage Regulators |  |  |  |  |  |  |  | LDO Voltage Regulators |  |  | 1.2mm |  | Torex | XC6220A331MR-G |  |  | 865-XC6220A331MR-G | https://www.mouser.co.uk/ProductDetail/Torex-Semiconductor/XC6220A331MR-G?qs=AsjdqWjXhJ8ZSWznL1J0gg%3D%3D

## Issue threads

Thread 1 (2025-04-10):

Lipsa frame-ului standard pentru schematic

sebihutanu, 2025-04-10:
Schematicul nu include un frame standard cu informații relevante precum numele proiectului, autor, dată etc. Deși nu este obligatoriu, adăugarea unui astfel de frame ajută la mentenanță/versionare.

Closed 2025-04-13.

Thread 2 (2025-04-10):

Lipsa delimitării clare între blocurile funcționale din schematic

sebihutanu, 2025-04-10:
În schematic nu există o delimitare vizuală clară a blocurilor funcționale (ex: USB, LDO, ESP32, SD Card, Battery Management etc). Deși nu este obligatoriu, este recomandat să existe o organizare mai clară pentru a facilita înțelegerea schemei electrice.

Closed 2025-04-13.

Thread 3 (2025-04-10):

Marcaje condensatori FFC greu vizibile

sebihutanu, 2025-04-10:
Marcajele condensatorilor din zona conectorului FFC nu sunt vizibile — acestea sunt fie acoperite, fie poziționate prea aproape de componentele din jur. Ar fi recomandat să fie repoziționate sau ajustate pentru o mai bună lizibilitate.

Closed 2025-04-13.

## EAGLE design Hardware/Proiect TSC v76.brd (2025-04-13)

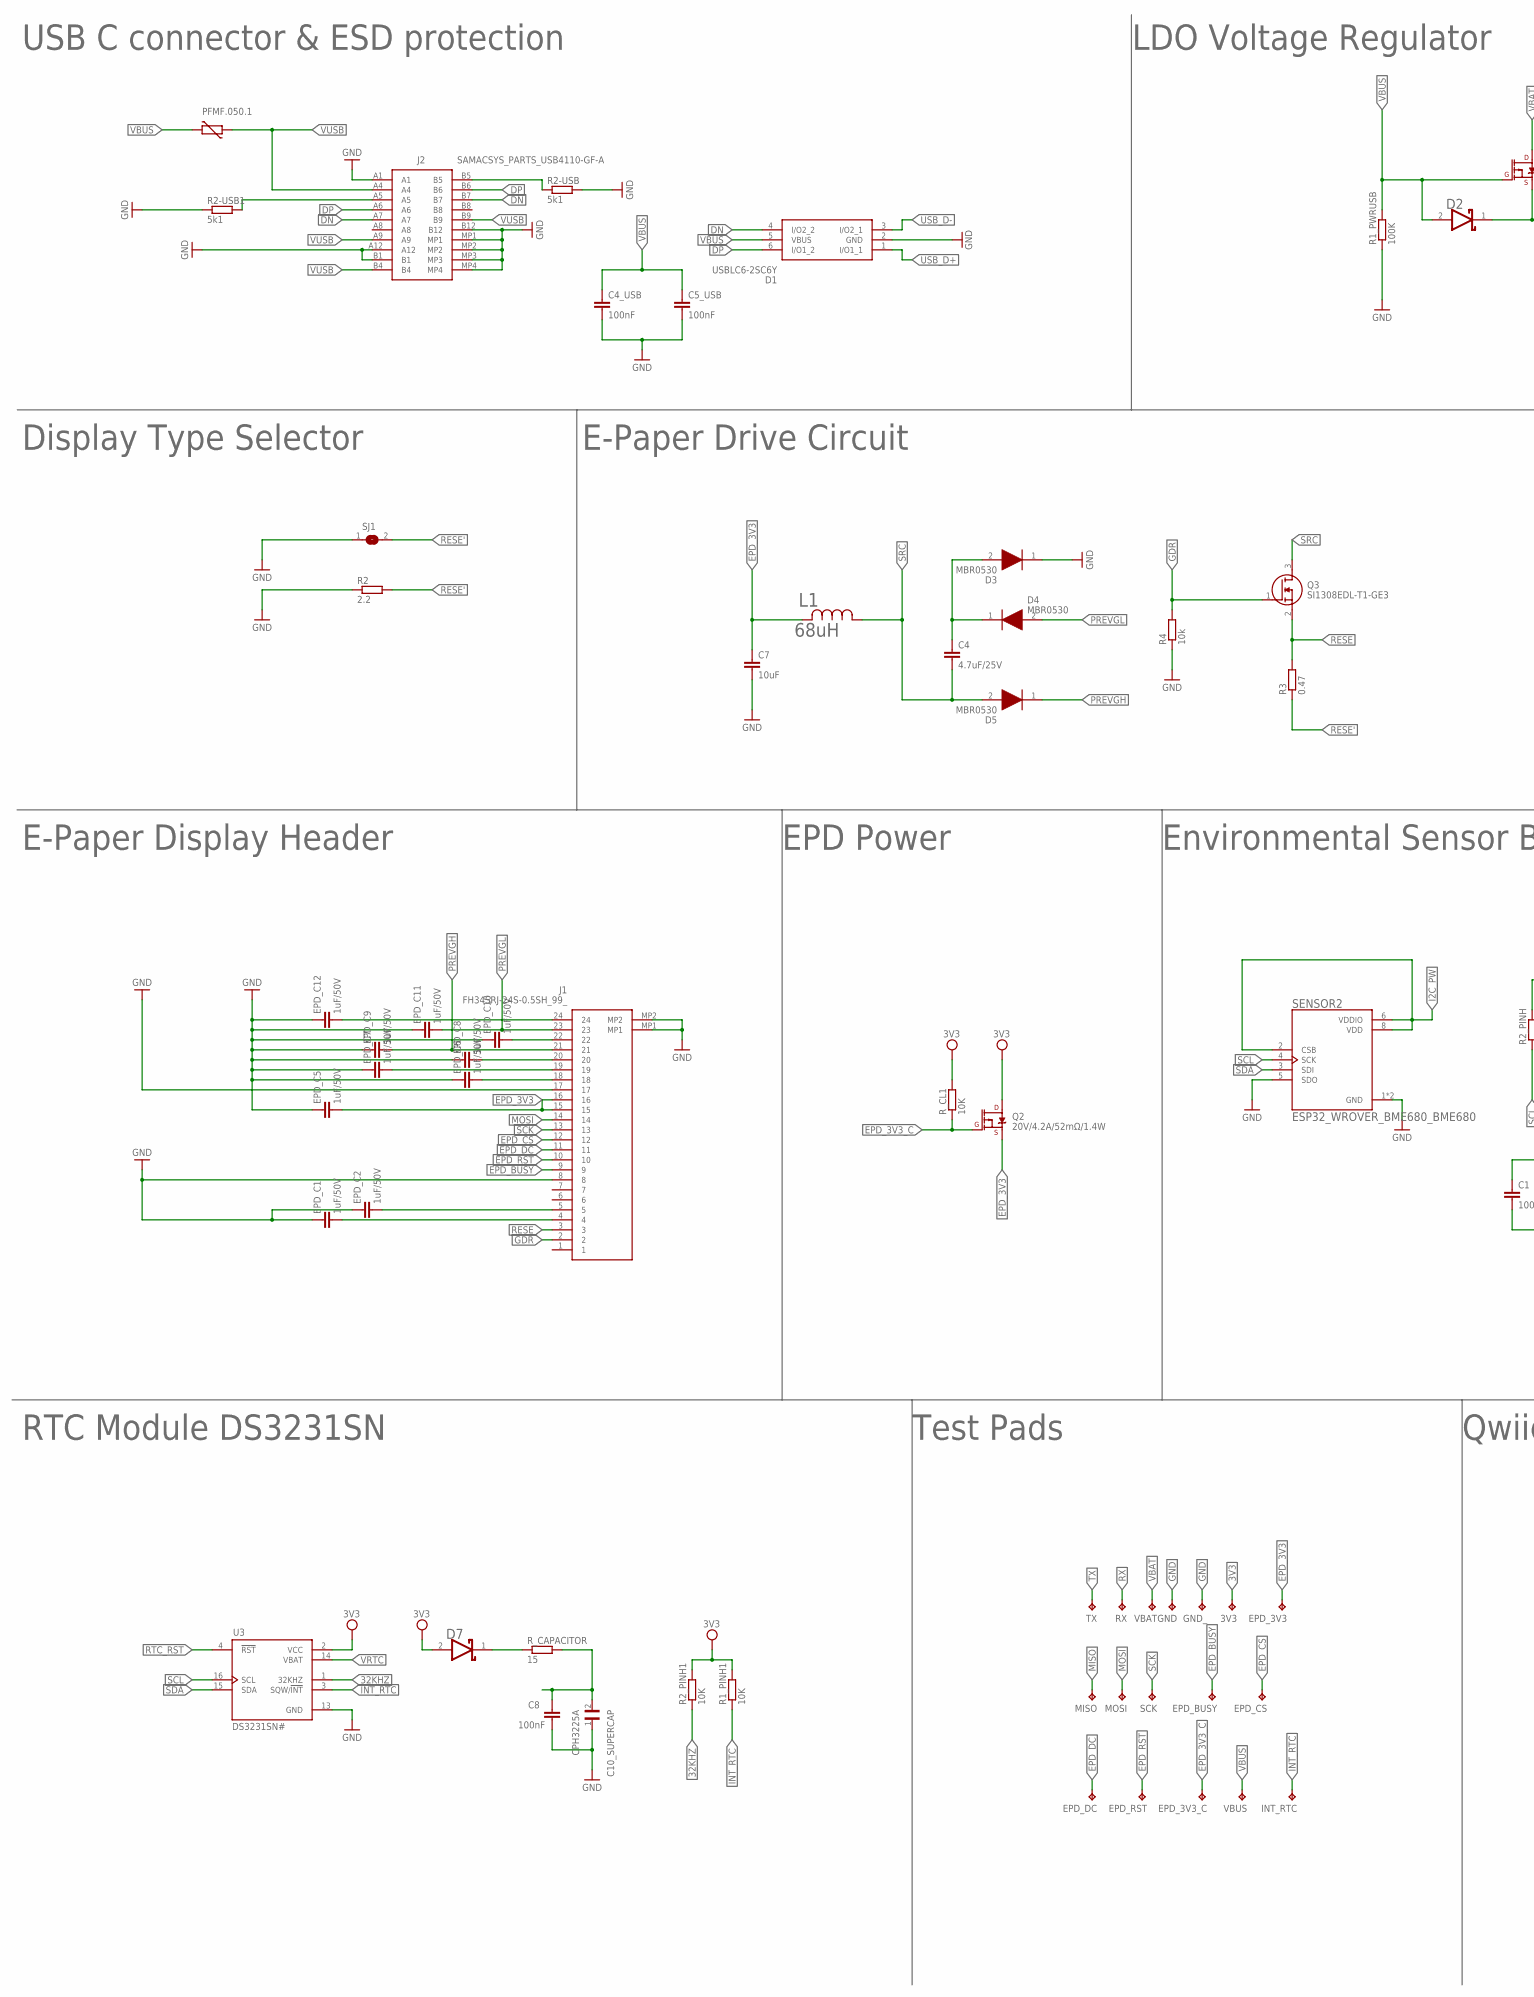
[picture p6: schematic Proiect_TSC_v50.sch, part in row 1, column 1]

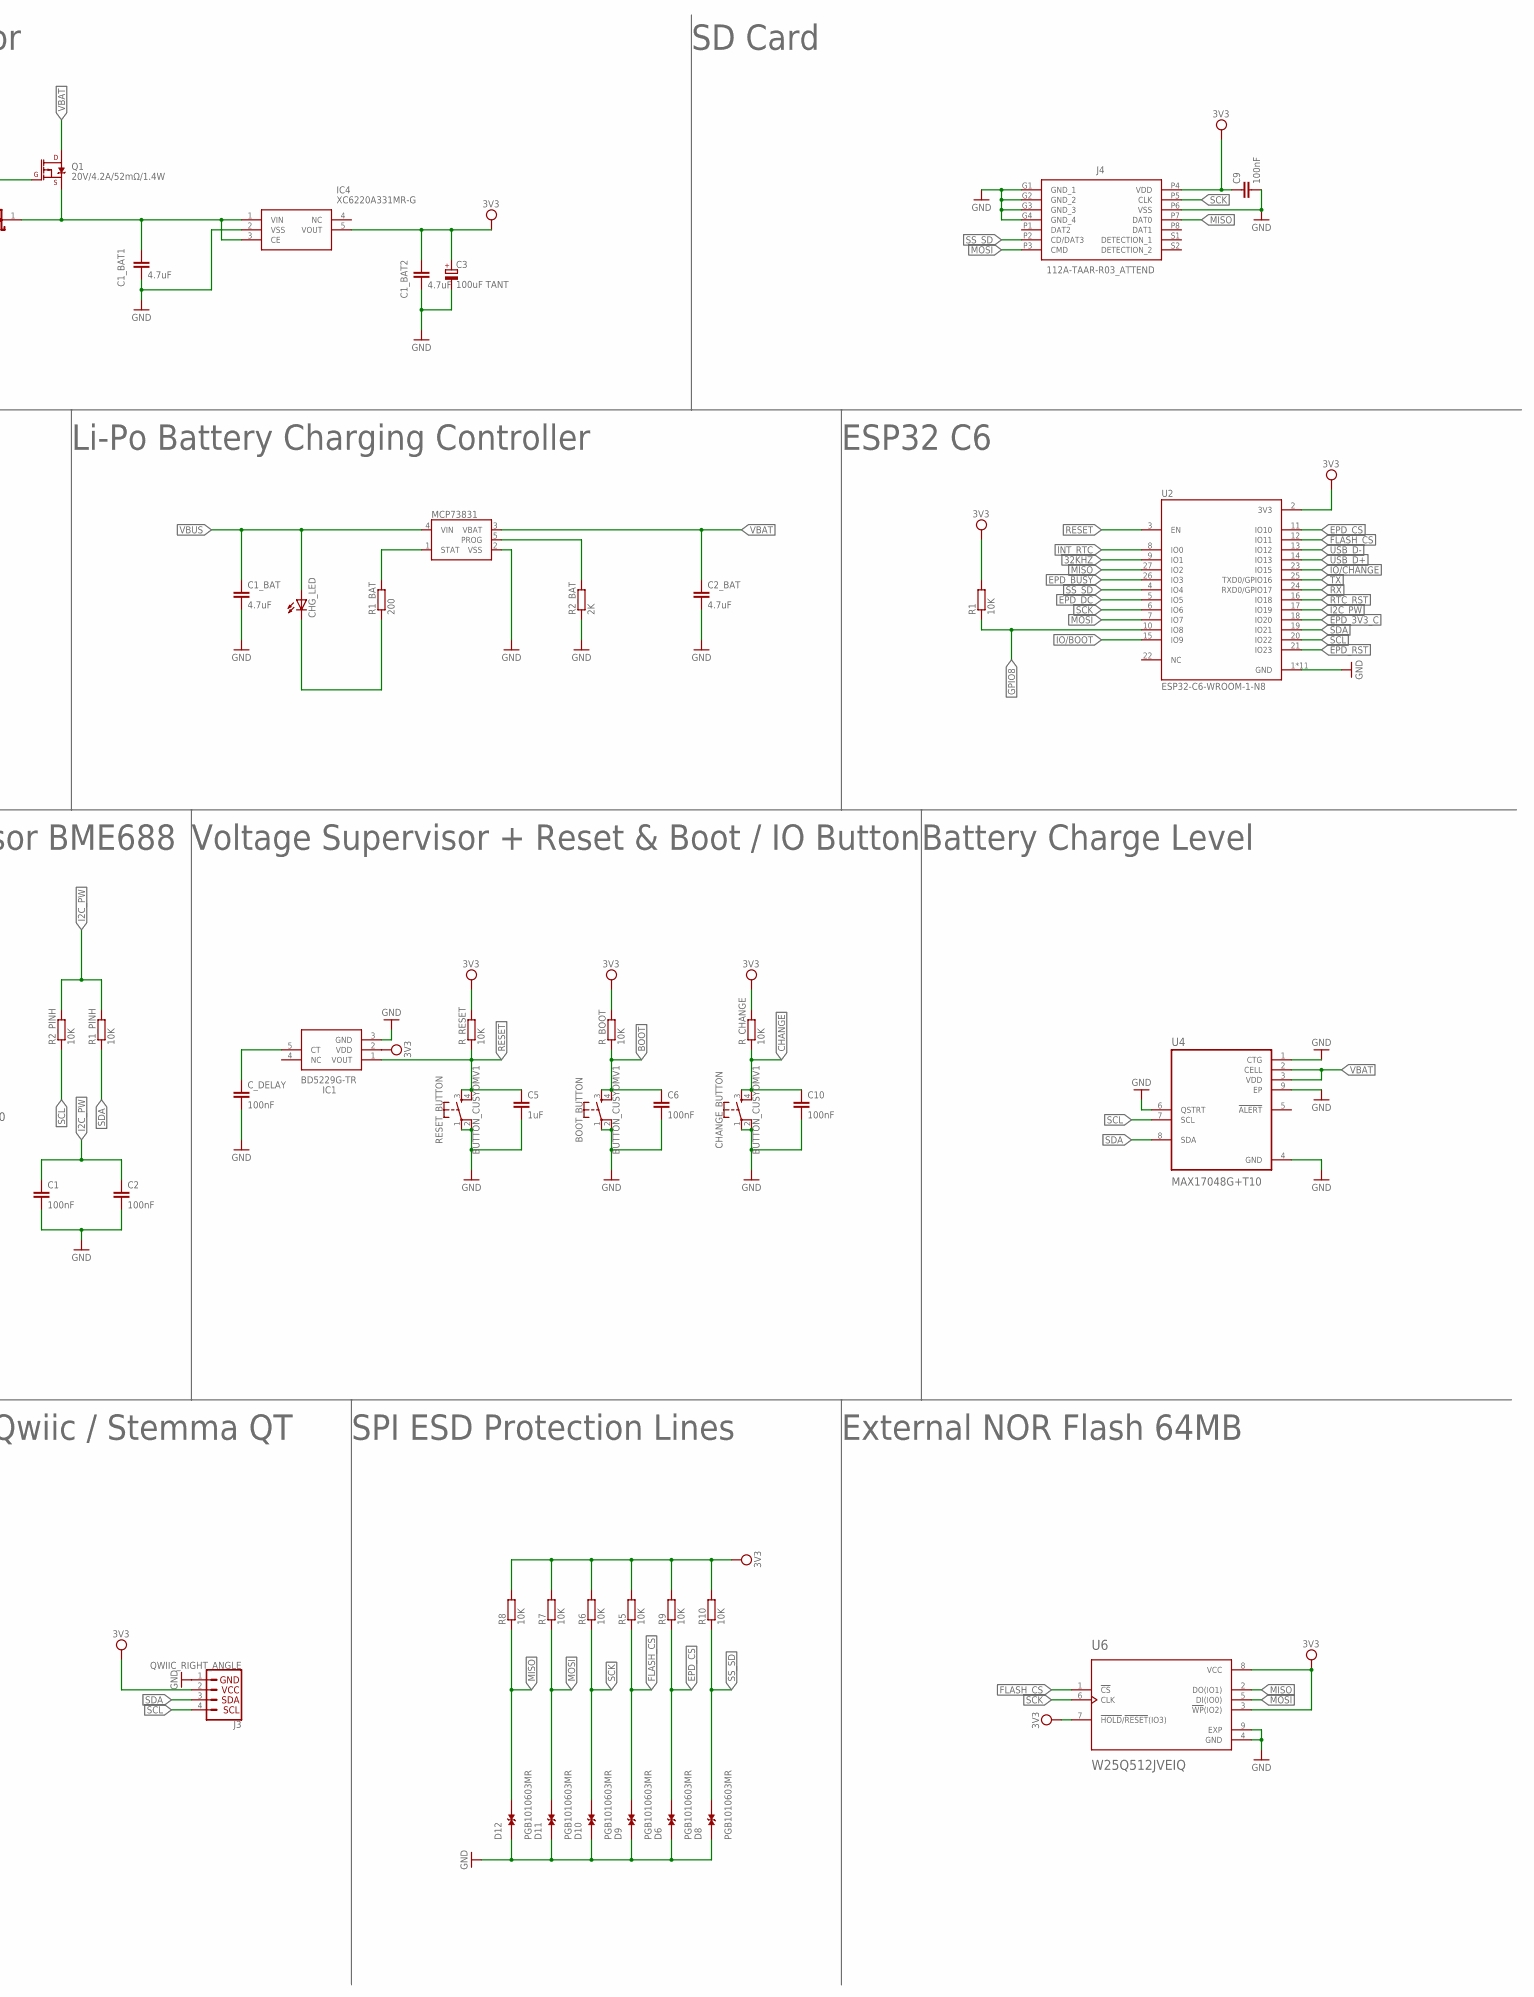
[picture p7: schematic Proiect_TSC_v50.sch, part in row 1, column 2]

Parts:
3V3: TPTP20R; TP20R
BOOT_BUTTON: BUTTON_CUSYOMV1; MYBUTTON
C1, C2, C4_USB, C5_USB, C9: 100nF; ESP32_WROVER_EAGLE-LTSPICE_C0402
C1_BAT, C1_BAT1, C1_BAT2, C2_BAT: 4.7uF; ESP32_WROVER_EAGLE-LTSPICE_C0402
C3: 100uF TANT; RCL_CT3528
C4: 4.7uF/25V; ESP32_WROVER_EAGLE-LTSPICE_C0402
C5: 1uF; EAGLE-LTSPICE_C0402
C6, C8, C10: 100nF; EAGLE-LTSPICE_C0402
C7: 10uF; EAGLE-LTSPICE_C0402
C10_SUPERCAP: CPH3225A; CAPCP3225X100N
CHANGE_BUTTON: BUTTON_CUSYOMV1; MYBUTTON
CHG_LED: ADAFRUIT_LEDCHIP-LED0603; ADAFRUIT_CHIP-LED0603
C_DELAY: 100nF; EAGLE-LTSPICE_C0402
D1: USBLC6-2SC6Y; SOT95P280X145-6N
D2, D7: ESP32_WROVER_AVX---SD0805S020S1R0_AVX_SD0805S020S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; ESP32_WROVER_AVX---SD0805S020S1R0_AVX_SD0805S020S1R0_0
D3, D4, D5: MBR0530; SOD3716X135N
D6, D8, D9, D10, D11, D12: PGB1010603MR; DIOC1608X36N
EPD_3V3, EPD_3V3_C: TPTP20R; TP20R
EPD_BUSY: TPTP20R; TP20R
EPD_C1, EPD_C2, EPD_C5, EPD_C6, EPD_C7, EPD_C8, EPD_C9, EPD_C10, EPD_C11, EPD_C12: 1uF/50V; ESP32_WROVER_EAGLE-LTSPICE_C0402
EPD_CS: TPTP20R; TP20R
EPD_DC: TPTP20R; TP20R
EPD_RST: TPTP20R; TP20R
GND: TPTP20R; TP20R
GND_: TPTP20R; TP20R
IC1: BD5229G-TR; SOT95P280X125-5N
IC4: XC6220A331MR-G; SOT95P280X120-5N
INT_RTC: TPTP20R; TP20R
J1: FH34SRJ-24S-0.5SH_99_; FH34SRJ24S05SH99
J2: SAMACSYS_PARTS_USB4110-GF-A; SAMACSYS_PARTS_USB4110GFA
J3: QWIIC_RIGHT_ANGLE; JST04_1MM_RA
J4: 112A-TAAR-R03_ATTEND; 112ATAARR03ATTEND
L1: 68uH; IND_4828-WE-TPC_WRE
MCP73831: ESP32_WROVER_SPARKFUN-IC-POWER_MCP73831; ESP32_WROVER_SPARKFUN-IC-POWER_SOT23-5
MISO: TPTP20R; TP20R
MOSI: TPTP20R; TP20R
PFMF.050.1: ESP32C6_VARISTORCN1812; ESP32C6_VARISTOR_CT/CN1812
Q1, Q2: 20V/4.2A/52mΩ/1.4W; ESP32_WROVER_SPARKFUN-DISCRETESEMI_SOT23-3
Q3: SI1308EDL-T1-GE3; SOT65P210X110-3N
R1, R1_PINH, R1_PINH1, R2_PINH, R2_PINH1, R5, R6, R7, R8, R9, R10: 10K; ESP32_WROVER_EAGLE-LTSPICE_R0402
R1_BAT: 200; ESP32_WROVER_EAGLE-LTSPICE_R0402
R1_PWRUSB: 100K; ESP32_WROVER_EAGLE-LTSPICE_R0402
R2: 2.2; ESP32_WROVER_EAGLE-LTSPICE_R0402
R2-USB, R2-USB1: 5k1; ESP32_WROVER_EAGLE-LTSPICE_R0402
R2_BAT: 2K; ESP32_WROVER_EAGLE-LTSPICE_R0402
R3: 0.47; ESP32_WROVER_EAGLE-LTSPICE_R0402
R4: 10k; ESP32_WROVER_EAGLE-LTSPICE_R0402
RESET_BUTTON: BUTTON_CUSYOMV1; MYBUTTON
RX: TPTP20R; TP20R
R_BOOT: 10K; ESP32_WROVER_EAGLE-LTSPICE_R0402
R_CAPACITOR: 15; ESP32_WROVER_EAGLE-LTSPICE_R0402
R_CHANGE: 10K; ESP32_WROVER_EAGLE-LTSPICE_R0402
R_CL1: 10K; ESP32_WROVER_EAGLE-LTSPICE_R0402
R_RESET: 10K; ESP32_WROVER_EAGLE-LTSPICE_R0402
SCK: TPTP20R; TP20R
SENSOR2: ESP32_WROVER_BME680_BME680; ESP32_WROVER_BME680_PSON80P300X300X100-8N
SJ1: SJ
TX: TPTP20R; TP20R
U2: ESP32-C6-WROOM-1-N8; XCVR_ESP32-C6-WROOM-1-N8
U3: DS3231SN#; SOIC127P1032X265-16N
U4: MAX17048G+T10; SON50P200X200X80-9N
U6: W25Q512JVEIQ; SON127P600X800X80-9N
VBAT: TPTP20R; TP20R
VBUS: TPTP20R; TP20R

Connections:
3V3: 3V3.TP, C1_BAT2.1, C3.+, C9.1, D7.2 (ANODE), IC1.2 (VDD), IC4.5 (VOUT), J3.2, J4.P4 (VDD), Q2.3 (D), R1.2, R1_PINH1.2, R2_PINH1.2, R5.2, R6.2, R7.2, R8.2, R9.2, R10.2, R_BOOT.2, R_CHANGE.2, R_CL1.2, R_RESET.2, U2.2 (3V3), U3.2 (VCC), U6.3 (!WP!(IO2)), U6.7 (!HOLD!/!RESET!(IO3)), U6.8 (VCC)
32KHZ: R2_PINH1.1, U2.9 (IO1), U3.1 (32KHZ)
BOOT: BOOT_BUTTON.3, BOOT_BUTTON.4, C6.1, R_BOOT.1
CHANGE: C10.1, CHANGE_BUTTON.3, CHANGE_BUTTON.4, R_CHANGE.1
DN: D1.4 (I/O2_2), J2.A7, J2.B7
DP: D1.6 (I/O1_2), J2.A6, J2.B6
EPD_3V3: C7.1, EPD_3V3.TP, EPD_C5.2, J1.15, J1.16, L1.2, Q2.2 (S)
EPD_3V3_C: EPD_3V3_C.TP, Q2.1 (G), R_CL1.1, U2.18 (IO20)
EPD_BUSY: EPD_BUSY.TP, J1.9, U2.26 (IO3)
EPD_CS: D6.2, EPD_CS.TP, J1.12, R9.1, U2.11 (IO10)
EPD_DC: EPD_DC.TP, J1.11, U2.5 (IO5)
EPD_RST: EPD_RST.TP, J1.10, U2.21 (IO23)
FLASH_CS: D9.2, R5.1, U2.12 (IO11), U6.1 (!CS)
GDR: J1.2, Q3.1 (G), R4.2
GND: BOOT_BUTTON.1, BOOT_BUTTON.2, C1.2, C1_BAT.2, C1_BAT1.2, C1_BAT2.2, C2.2, C2_BAT.2, C3.-, C4_USB.2, C5.2, C5_USB.2, C6.2, C7.2, C8.2, C9.2, C10.2, C10_SUPERCAP.1, CHANGE_BUTTON.1, CHANGE_BUTTON.2, C_DELAY.2, D1.2 (GND), D3.1 (K), D6.1, D8.1, D9.1, D10.1, D11.1, D12.1, EPD_C1.1, EPD_C2.1, EPD_C5.1, EPD_C6.1, EPD_C7.1, EPD_C8.1, EPD_C9.1, EPD_C10.1, EPD_C11.1, EPD_C12.1, GND.TP, GND_.TP, IC1.3 (GND), IC4.2 (VSS), J1.8, J1.17, J1.MP1, J1.MP2, J2.A1, J2.A12, J2.B1, J2.B12, J2.MP1, J2.MP2, J2.MP3, J2.MP4, J3.1, J4.G1 (GND_1), J4.G2 (GND_2), J4.G3 (GND_3), J4.G4 (GND_4), J4.P6 (VSS), MCP73831.2 (VSS), R1_PWRUSB.1, R2.1, R2-USB.2, R2-USB1.1, R2_BAT.1, R4.1, RESET_BUTTON.1, RESET_BUTTON.2, SENSOR2.1 (GND), SENSOR2.5 (SDO), SENSOR2.7 (GND), SJ1.1, U2.1 (GND), U2.28 (GND), U2.29_1 (GND), U2.29_2 (GND), U2.29_3 (GND), U2.29_4 (GND), U2.29_5 (GND), U2.29_6 (GND), U2.29_7 (GND), U2.29_8 (GND), U2.29_9 (GND), U3.13 (GND), U4.1 (CTG), U4.4 (GND), U4.6 (QSTRT), U4.9 (EP), U6.4 (GND), U6.9 (EXP)
GPIO8: R1.1, U2.10 (IO8)
I2C_PW: C1.1, C2.1, R1_PINH.2, R2_PINH.2, SENSOR2.2 (CSB), SENSOR2.6 (VDDIO), SENSOR2.8 (VDD), U2.17 (IO19)
INT_RTC: INT_RTC.TP, R1_PINH1.1, U2.8 (IO0), U3.3 (SQW/!INT)
IO/BOOT: U2.15 (IO9)
IO/CHANGE: U2.23 (IO15)
MISO: D12.2, J4.P7 (DAT0), MISO.TP, R8.1, U2.27 (IO2), U6.2 (DO(IO1))
MOSI: D11.2, J1.14, J4.P3 (CMD), MOSI.TP, R7.1, U2.7 (IO7), U6.5 (DI(IO0))
unnamed: J2.A5, R2-USB1.2
unnamed: J2.B5, R2-USB.1
unnamed: C_DELAY.1, IC1.5 (CT)
unnamed: C1_BAT1.1, D2.1 (CATHODE), IC4.1 (VIN), IC4.3 (CE), Q1.2 (S)
unnamed: MCP73831.5 (PROG), R2_BAT.2
unnamed: D7.1 (CATHODE), R_CAPACITOR.1
unnamed: C4.1, D3.2 (A), D4.1 (K)
unnamed: EPD_C12.2, J1.24
unnamed: MCP73831.1 (STAT), R1_BAT.2
unnamed: CHG_LED.C, R1_BAT.1
unnamed: C8.1, C10_SUPERCAP.2, R_CAPACITOR.2
unnamed: EPD_C10.2, J1.22
unnamed: EPD_C8.2, J1.20
unnamed: EPD_C7.2, J1.19
unnamed: EPD_C6.2, J1.18
unnamed: EPD_C2.2, J1.5
unnamed: EPD_C1.2, J1.4
PREVGH: D5.1 (K), EPD_C9.2, J1.21
PREVGL: D4.2 (A), EPD_C11.2, J1.23
RESE: J1.3, Q3.2 (S), R3.2
RESE': R2.2, R3.1, SJ1.2
RESET: C5.1, IC1.1 (VOUT), RESET_BUTTON.3, RESET_BUTTON.4, R_RESET.1, U2.3 (EN)
RTC_RST: U2.16 (IO18), U3.4 (!RST)
RX: RX.TP, U2.24 (RXD0/GPIO17)
SCK: D10.2, J1.13, J4.P5 (CLK), R6.1, SCK.TP, U2.6 (IO6), U6.6 (CLK)
SCL: J3.4, R2_PINH.1, SENSOR2.4 (SCK), U2.20 (IO22), U3.16 (SCL), U4.7 (SCL)
SDA: J3.3, R1_PINH.1, SENSOR2.3 (SDI), U2.19 (IO21), U3.15 (SDA), U4.8 (SDA)
SRC: C4.2, D5.2 (A), L1.1, Q3.3 (D)
SS_SD: D8.2, J4.P2 (CD/DAT3), R10.1, U2.4 (IO4)
TX: TX.TP, U2.25 (TXD0/GPIO16)
USB_D+: D1.1 (I/O1_1), U2.14 (IO13)
USB_D-: D1.3 (I/O2_1), U2.13 (IO12)
VBAT: C2_BAT.1, MCP73831.3 (VBAT), Q1.3 (D), U4.2 (CELL), U4.3 (VDD), VBAT.TP
VBUS: C1_BAT.1, C4_USB.1, C5_USB.1, CHG_LED.A, D1.5 (VBUS), D2.2 (ANODE), MCP73831.4 (VIN), PFMF.050.1.2, Q1.1 (G), R1_PWRUSB.2, VBUS.TP
VRTC: U3.14 (VBAT)
VUSB: J2.A4, J2.A9, J2.B4, J2.B9, PFMF.050.1.1

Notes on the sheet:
USB C connector & ESD protection
LDO Voltage Regulator
SD Card
Display Type Selector
E-Paper Display Header
ESP32 C6
E-Paper Drive Circuit
Li-Po Battery Charging Controller
EPD Power
Environmental Sensor BME688
Voltage Supervisor + Reset & Boot / IO Button
Battery Charge Level
RTC Module DS3231SN
Test Pads
Qwiic / Stemma QT
SPI ESD Protection Lines
External NOR Flash 64MB

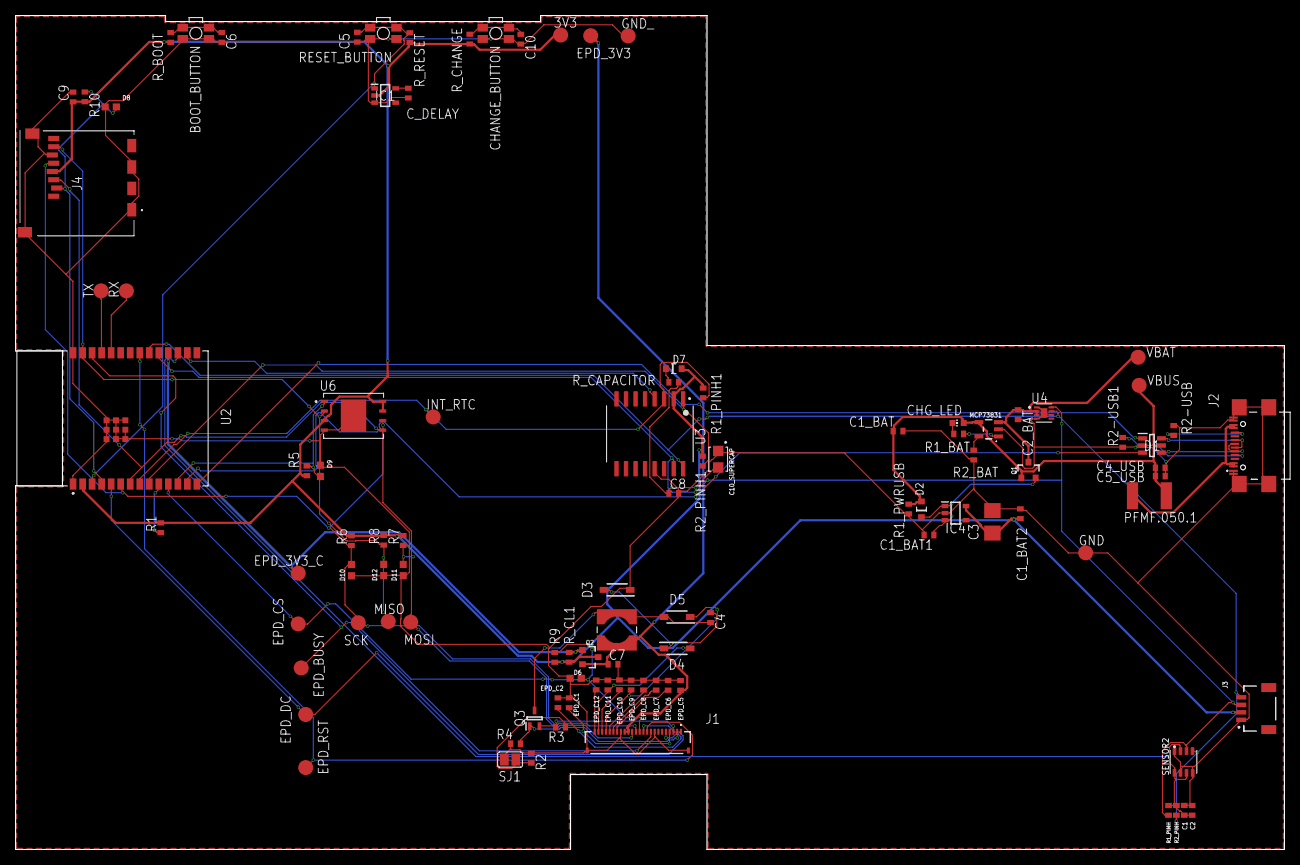
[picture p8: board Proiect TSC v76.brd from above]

Board: 2 copper layers, 169.2 x 111.2 mm, 103 parts (0 on the bottom side), 55 nets.

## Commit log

2025-04-05 upload proiect TSC (part 1)
    [PnP_Proiect TSC v74_front.csv, Proiect TSC v74.brd, Proiect TSC v74.csv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]
2025-04-13 Delete Hardware/Proiect_TSC_v48.sch
    Pentru rezolvarea primelor doua issueuri, trebuie sa stergem versiunea precedenta a fisierului schematic
    [Proiect_TSC_v48.sch]
2025-04-13 Rezolvare issue #1 si issue #2
    Am modificat fisierul schematic astfel incat acesta sa includa frameul standard (marit astfel incat sa incapa toate componentele din fisa schematica) si am facut si delimitare clara a blocurilor functionale, astfel incat sa existe o intelegere mai clara a schemei electrice. De asemenea, pentru fiecare bloc functional, am pus si numele acestuia.
    [Proiect_TSC_v50.sch]
2025-04-13 Delete Hardware/Proiect TSC v74.brd
    Pentru rezolvarea issuerilor #3, #4 si #5, trebuie stearsa versiunea veche a fisierului cu boardul
    [Proiect TSC v74.brd]
2025-04-13 Rezolvare la issuerile #3, #4 si #5
    In aceasta versiune modificata, am micsorat marcajele de la condensatorii FFC, astfel incat acesta sa fie lizibil, am schimbat numele testpadurilor, in asa fel incat sa aiba denumirea semnalelor corespunzatoare pentru fiecare testpad, si am schimbat grosimea PCB-ului la 1 mm, asa cum e recomandat in cerintele proiectului.
    [Proiect TSC v76.brd]
2025-04-13 Rezolvarea issueului #7
    Am modificat modelul tabletei OpenBook, astfel incat componentele PCB-ului sa fie redirectionate catre display si sa ne asiguram ca pozitionarea componentelor este una corecta.

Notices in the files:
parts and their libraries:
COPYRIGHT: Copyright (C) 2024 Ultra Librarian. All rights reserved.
